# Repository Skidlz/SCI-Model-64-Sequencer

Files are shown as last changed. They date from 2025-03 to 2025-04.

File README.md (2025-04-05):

# SCI-Model-64-Sequencer
Sequential Circuits Model 64 Sequencer for Commodore 64

## Parts
At the time or writing, most of the parts are still available at Jameco.

They offer the H11L1 can be used in place of the PC900, and 68B21 instead of the 68A21.

## Schematic

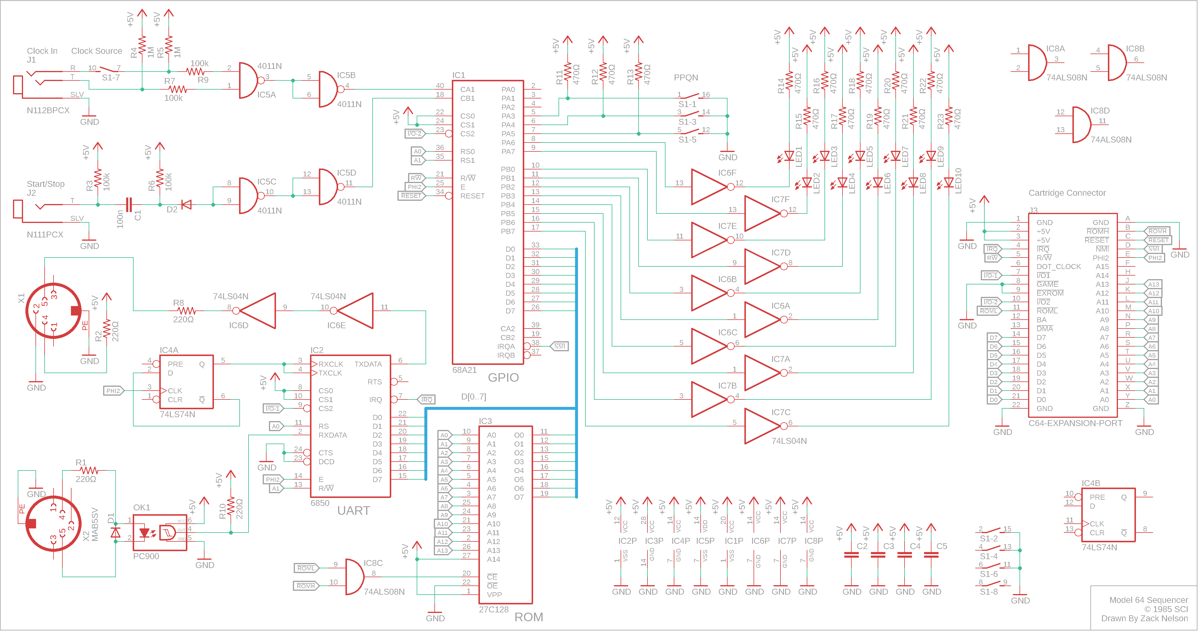
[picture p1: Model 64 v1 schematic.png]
Schematic


## PCB
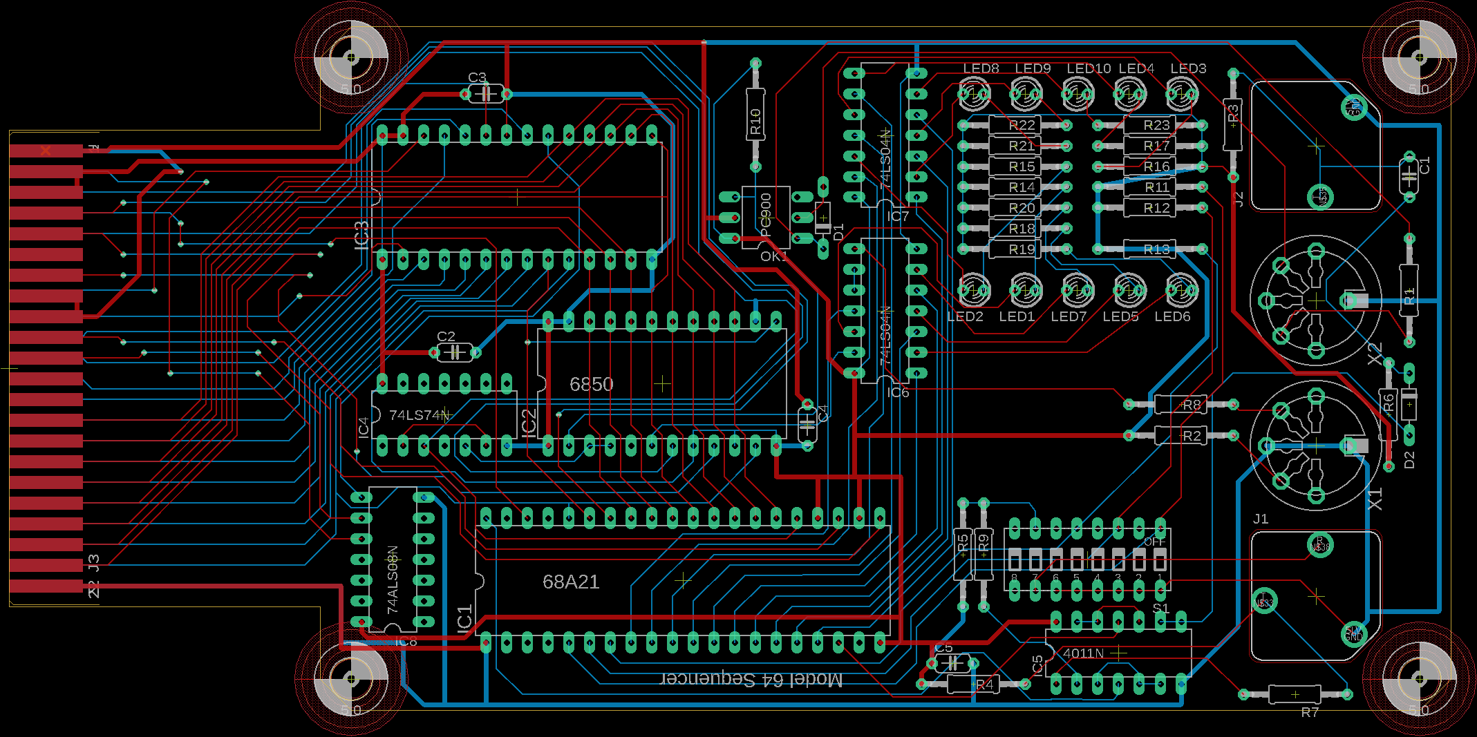
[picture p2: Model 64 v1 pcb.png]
PCB


## Case
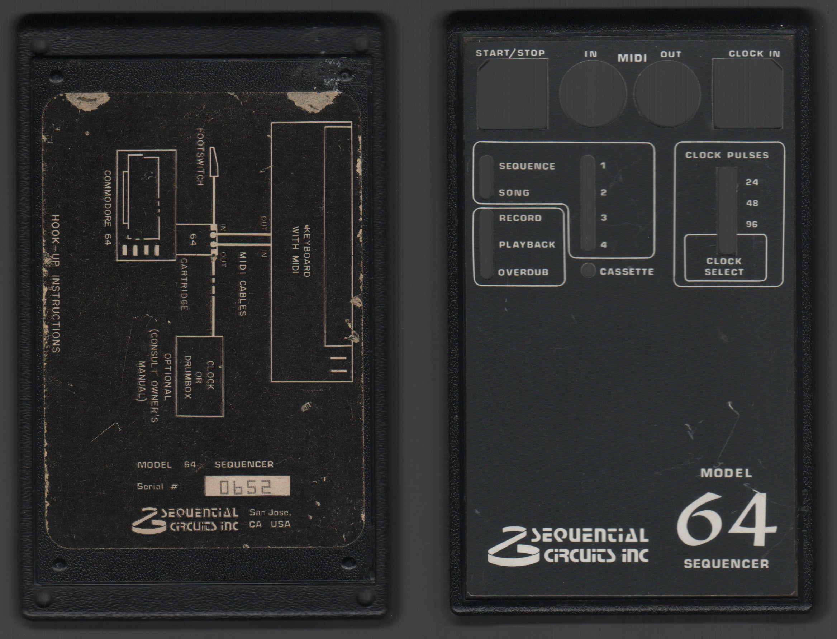
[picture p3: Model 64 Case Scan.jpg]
Case


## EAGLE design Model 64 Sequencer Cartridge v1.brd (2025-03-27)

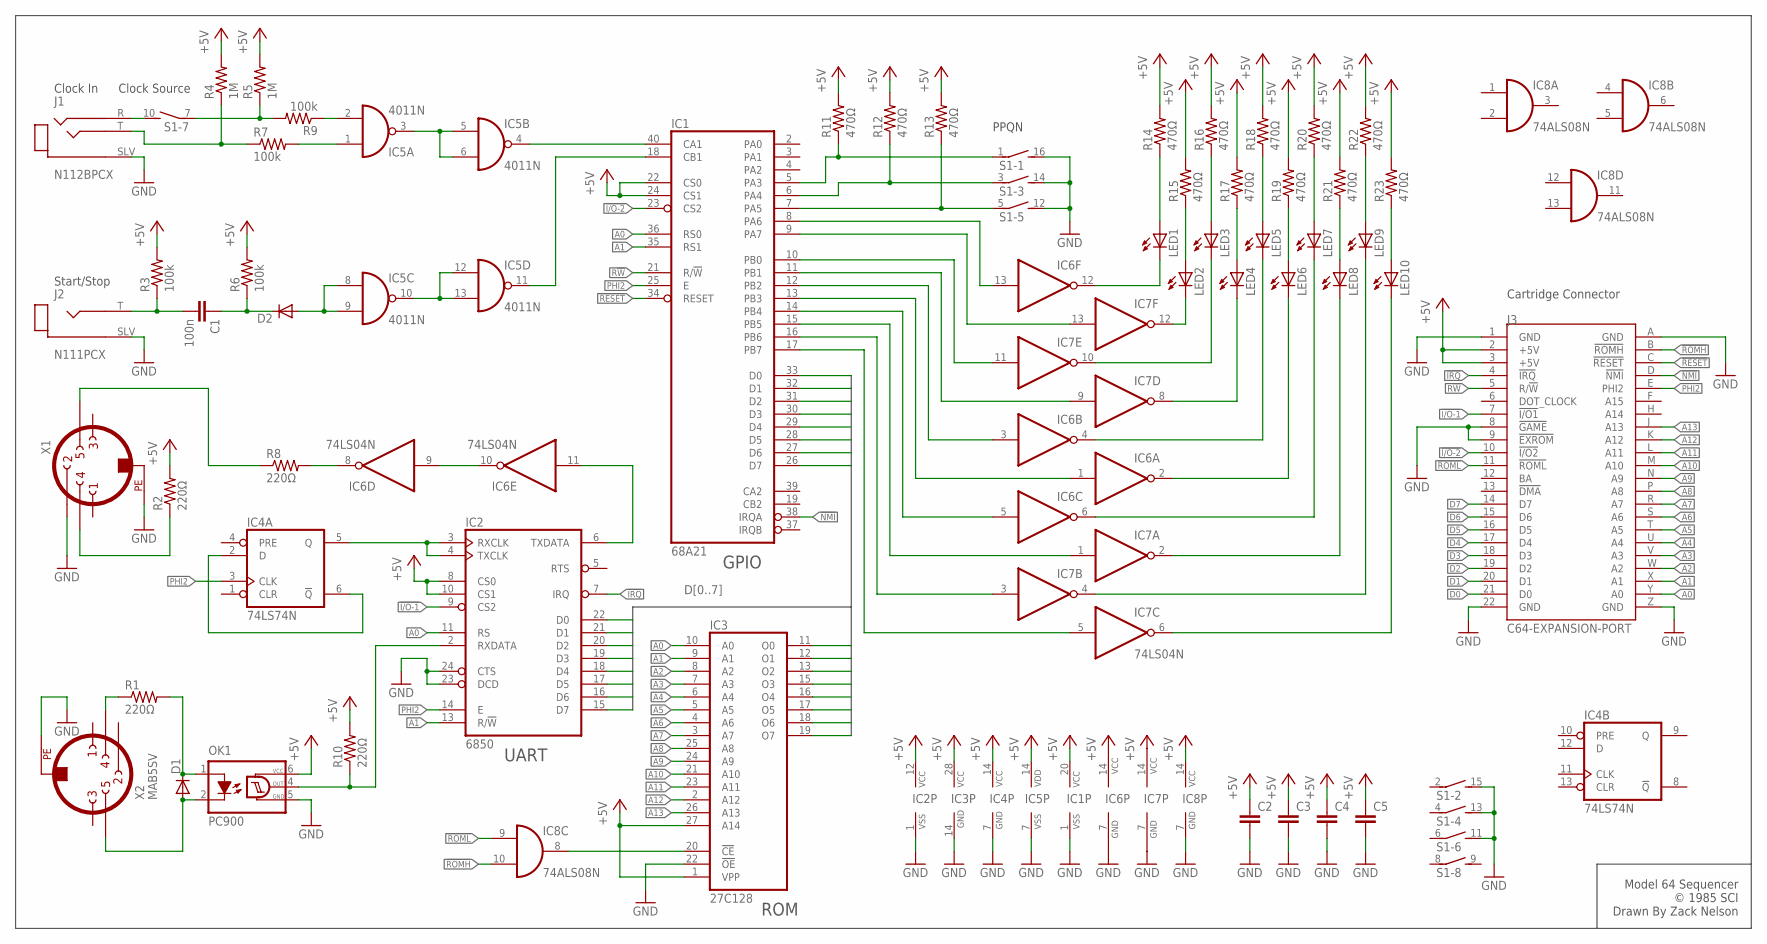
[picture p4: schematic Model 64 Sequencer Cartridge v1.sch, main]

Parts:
C1: 100n; C050-024X044
C2, C3, C4, C5: C-EU050-024X044; C050-024X044
D1, D2: DIODE-D-7.5; D-7.5
IC1: 68A21; DIL40
IC2: 6850; DIL24
IC3: 27C128; DIL28
IC4: 74LS74N; DIL14
IC5: 4011N; DIL14
IC6, IC7: 74LS04N; DIL14
IC8: 74ALS08N; DIL14
J1: N112BPCX; SWITCHCRAFT_N112BPCX
J2: N111PCX; SWITCHCRAFT_N111PCX
J3: C64-EXPANSION-PORT; EXPANSIO_SQ
LED1, LED2, LED3, LED4, LED5, LED6, LED7, LED8, LED9, LED10: LED3MM
OK1: PC900; DIL06
R1, R2, R8, R10: 220Ω; 0207/12
R3, R6, R7, R9: 100k; 0207/12
R4, R5: 1M; 0207/12
R11, R12, R13, R14, R15, R16, R17, R18, R19, R20, R21, R22, R23: 470Ω; 0207/12
S1: DIP08S
X1, X2: MAB5SV

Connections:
!I/O-1: IC2.9 (CS2), J3.7 (!I/O1)
!I/O-2: IC1.23 (CS2), J3.10 (!I/O2)
!IRQ: IC2.7 (IRQ), J3.4 (!IRQ)
!NMI: IC1.38 (IRQA), J3.D (!NMI)
!RESET: IC1.34 (RESET), J3.C (!RESET)
!ROMH: IC8.10 (I1), J3.B (!ROMH)
!ROML: IC8.9 (I0), J3.11 (!ROML)
+5V: C2.1, C3.1, C4.1, C5.1, IC1.20 (VCC), IC1.22 (CS0), IC1.24 (CS1), IC2.8 (CS0), IC2.10 (CS1), IC2.12 (VCC), IC3.1 (VPP), IC3.27 (A14), IC3.28 (VCC), IC4.14 (VCC), IC5.14 (VDD), IC6.14 (VCC), IC7.14 (VCC), IC8.14 (VCC), J3.2 (+5V), J3.3 (+5V), OK1.6 (VCC), R2.2, R3.2, R4.2, R5.2, R6.2, R10.2, R11.2, R12.2, R13.2, R14.2, R15.2, R16.2, R17.2, R18.2, R19.2, R20.2, R21.2, R22.2, R23.2
A0: IC1.36 (RS0), IC2.11 (RS), IC3.10 (A0), J3.Y (A0)
A1: IC1.35 (RS1), IC2.13 (R/!W), IC3.9 (A1), J3.X (A1)
A2: IC3.8 (A2), J3.W (A2)
A3: IC3.7 (A3), J3.V (A3)
A4: IC3.6 (A4), J3.U (A4)
A5: IC3.5 (A5), J3.T (A5)
A6: IC3.4 (A6), J3.S (A6)
A7: IC3.3 (A7), J3.R (A7)
A8: IC3.25 (A8), J3.P (A8)
A9: IC3.24 (A9), J3.N (A9)
A10: IC3.21 (A10), J3.M (A10)
A11: IC3.23 (A11), J3.L (A11)
A12: IC3.2 (A12), J3.K (A12)
A13: IC3.26 (A13), J3.J (A13)
D0: IC1.33 (D0), IC2.22 (D0), IC3.11 (O0), J3.21 (D0)
D1: IC1.32 (D1), IC2.21 (D1), IC3.12 (O1), J3.20 (D1)
D2: IC1.31 (D2), IC2.20 (D2), IC3.13 (O2), J3.19 (D2)
D3: IC1.30 (D3), IC2.19 (D3), IC3.15 (O3), J3.18 (D3)
D4: IC1.29 (D4), IC2.18 (D4), IC3.16 (O4), J3.17 (D4)
D5: IC1.28 (D5), IC2.17 (D5), IC3.17 (O5), J3.16 (D5)
D6: IC1.27 (D6), IC2.16 (D6), IC3.18 (O6), J3.15 (D6)
D7: IC1.26 (D7), IC2.15 (D7), IC3.19 (O7), J3.14 (D7)
GND: C2.2, C3.2, C4.2, C5.2, IC1.1 (VSS), IC2.1 (VSS), IC2.23 (DCD), IC2.24 (CTS), IC3.14 (GND), IC3.22 (!OE), IC4.7 (GND), IC5.7 (VSS), IC6.7 (GND), IC7.7 (GND), IC8.7 (GND), J1.SLV (SLEEVE), J2.SLV (SLEEVE), J3.1 (GND), J3.8 (!GAME), J3.9 (!EXROM), J3.22 (GND), J3.A (GND), J3.Z (GND), OK1.5 (GND), S1.11 (2), S1.12 (2), S1.13 (2), S1.14 (2), S1.15 (2), S1.16 (2), X1.2, X1.PE, X2.PE
unnamed: IC2.3 (RXCLK), IC2.4 (TXCLK), IC4.5 (Q)
unnamed: R2.1, X1.4
unnamed: IC2.6 (TXDATA), IC6.11 (I)
unnamed: IC4.2 (D), IC4.6 (!Q)
unnamed: IC6.9 (I), IC6.10 (O)
unnamed: IC6.8 (O), R8.2
unnamed: IC1.13 (PB3), IC6.1 (I)
unnamed: IC5.3 (O), IC5.5 (I0), IC5.6 (I1)
unnamed: D2.A, IC5.8 (I0), IC5.9 (I1)
unnamed: IC5.10 (O), IC5.12 (I0), IC5.13 (I1)
unnamed: IC1.18 (CB1), IC5.11 (O)
unnamed: IC1.40 (CA1), IC5.4 (O)
unnamed: IC5.1 (I0), R7.2
unnamed: LED6.A, R19.1
unnamed: LED5.A, R18.1
unnamed: LED7.A, R20.1
unnamed: LED1.A, R14.1
unnamed: LED2.A, R15.1
unnamed: LED8.A, R21.1
unnamed: LED9.A, R22.1
unnamed: IC7.2 (O), LED8.K (C)
unnamed: IC7.4 (O), LED9.K (C)
unnamed: IC7.6 (O), LED10.K (C)
unnamed: IC7.8 (O), LED4.K (C)
unnamed: IC7.10 (O), LED3.K (C)
unnamed: IC7.12 (O), LED2.K (C)
unnamed: LED10.A, R23.1
unnamed: LED4.A, R17.1
unnamed: LED3.A, R16.1
unnamed: IC1.5 (PA3), R11.1, S1.1
unnamed: IC1.6 (PA4), R12.1, S1.3 (1)
unnamed: IC1.7 (PA5), R13.1, S1.5 (1)
unnamed: J1.T (TIP), R4.1, R7.1
unnamed: C1.1, D2.C, R6.1
unnamed: C1.2, J2.T (TIP), R3.1
unnamed: IC5.2 (I1), R9.1
unnamed: R5.1, R9.2, S1.7 (1)
unnamed: J1.R (RING), S1.10 (2)
unnamed: D1.A, OK1.2 (C), X2.5
unnamed: D1.C, OK1.1 (A), R1.2
unnamed: IC2.2 (RXDATA), OK1.4 (OUT), R10.1
unnamed: IC6.12 (O), LED1.K (C)
unnamed: IC1.15 (PB5), IC7.1 (I)
unnamed: IC1.9 (PA7), IC7.13 (I)
unnamed: IC1.16 (PB6), IC7.3 (I)
unnamed: IC1.17 (PB7), IC7.5 (I)
unnamed: IC1.11 (PB1), IC7.9 (I)
unnamed: IC1.10 (PB0), IC7.11 (I)
unnamed: IC1.8 (PA6), IC6.13 (I)
unnamed: IC6.6 (O), LED7.K (C)
unnamed: IC1.14 (PB4), IC6.5 (I)
unnamed: IC1.12 (PB2), IC6.3 (I)
unnamed: IC6.4 (O), LED5.K (C)
unnamed: IC6.2 (O), LED6.K (C)
unnamed: R8.1, X1.5
unnamed: R1.1, X2.4
unnamed: IC3.20 (!CE), IC8.8 (O)
PHI2: IC1.25 (E), IC2.14 (E), IC4.3 (CLK), J3.E (PHI2)
R!W: IC1.21 (R/!W), J3.5 (R/!W)

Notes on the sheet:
Model 64 Sequencer © 1985 SCI Drawn By Zack Nelson
UART
ROM
GPIO
PPQN
Clock Source
Start/Stop
Clock In
Cartridge Connector

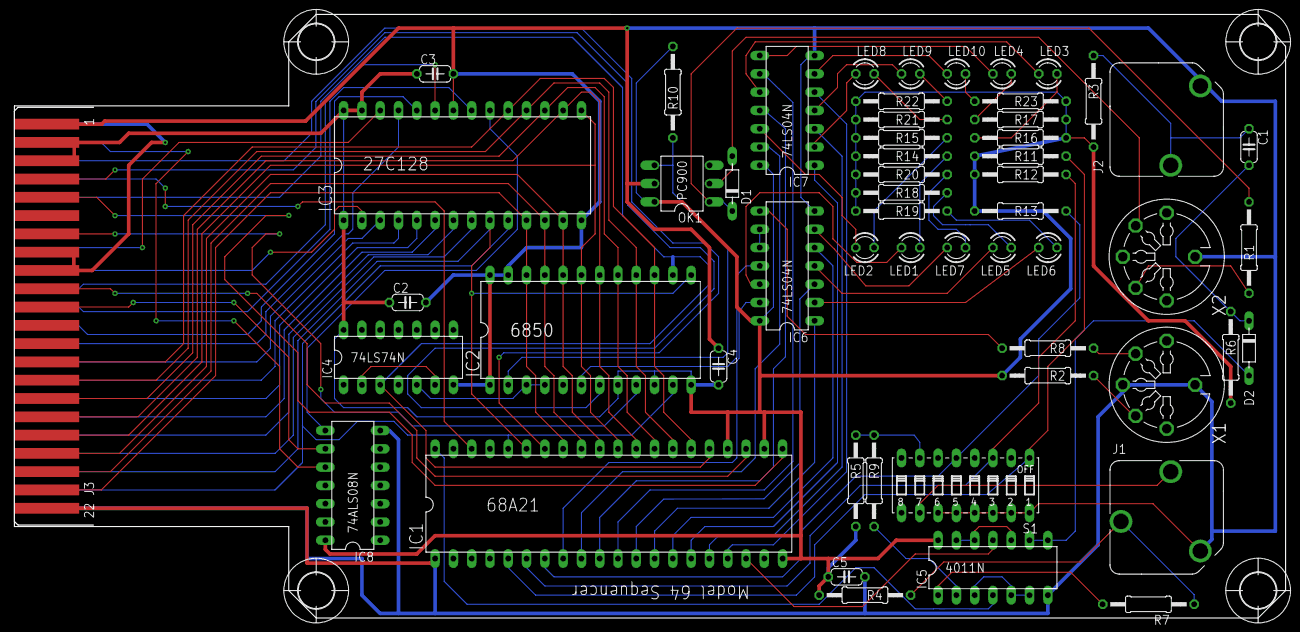
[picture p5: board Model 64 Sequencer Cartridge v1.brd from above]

Board: 2 copper layers, 176.5 x 83.8 mm, 59 parts (0 on the bottom side), 90 nets.

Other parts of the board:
U$1, U$2, U$3, U$4: 5,0

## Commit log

2025-03-26 Update to use 6.35mm jacks
    [Model 64 Sequencer Cartridge v1.brd, Model 64 Sequencer Cartridge v1.sch]
2025-03-27 Fixing names on wrong layer
    [Model 64 Sequencer Cartridge v1.brd]
